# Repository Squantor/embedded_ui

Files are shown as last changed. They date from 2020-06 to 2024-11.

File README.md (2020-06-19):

# General purpose embedded user interface
This repository contains the files for a general purpose embedded system user interface.
## Structure
* [Electronics](https://github.com/Squantor/embedded_ui/blob/master/electronics/README.md) contains the UI PCB with LCD and buttons
* [Software](https://github.com/Squantor/embedded_ui/blob/master/software/README.md) contains the test and demo software for the user interface
* [Mechanical](https://github.com/Squantor/embedded_ui/blob/master/mechanical/README.md) contains drawings of UI covers
## Checking out
This project makes extensive use of submodules, use ```git clone --recurse-submodules https://github.com/Squantor/$(PROJECT).git``` to clone the repository and its submodules in one go.

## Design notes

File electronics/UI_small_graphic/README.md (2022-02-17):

# Small graphical user interface
This PCB is a small graphical user interface with a few buttons.
# HSI (Hardware Software Interface)
This applies to a project that has a embedded software component. Describe what each pin/bus does, what it is connected to, what its function is and some "safe" behaviour when starting up.
## TODO's
Still some things need to be done:
* Produce at [Aisler](https://aisler.net/)
* Assemble
* Test & characterise
* update Readme.md with pictures and BOM
## BOM
* The standard aliexpress OLED displays with 128x64 or 128x32 resolution.
* I2C port expander (PCF device)
## Pictures
TODO

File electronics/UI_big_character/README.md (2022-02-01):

# Big character user interface
User interface for the a wide range of applications consisting of a 2 by 16 character LCD, 4 buttons and a rotary encoder.
## TODO's
* Assemble
* Test & characterise
* update Readme.md with pictures and BOM

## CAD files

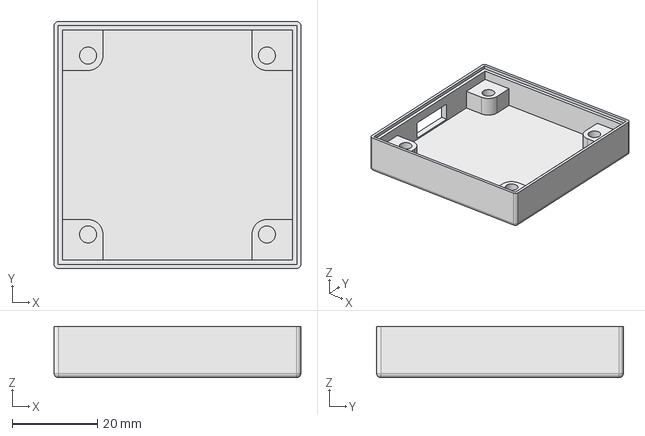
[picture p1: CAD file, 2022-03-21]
mechanical/UI_small_graphic_box/UI_small_graphic.FCStd
58.0 x 58.0 x 12.0 mm

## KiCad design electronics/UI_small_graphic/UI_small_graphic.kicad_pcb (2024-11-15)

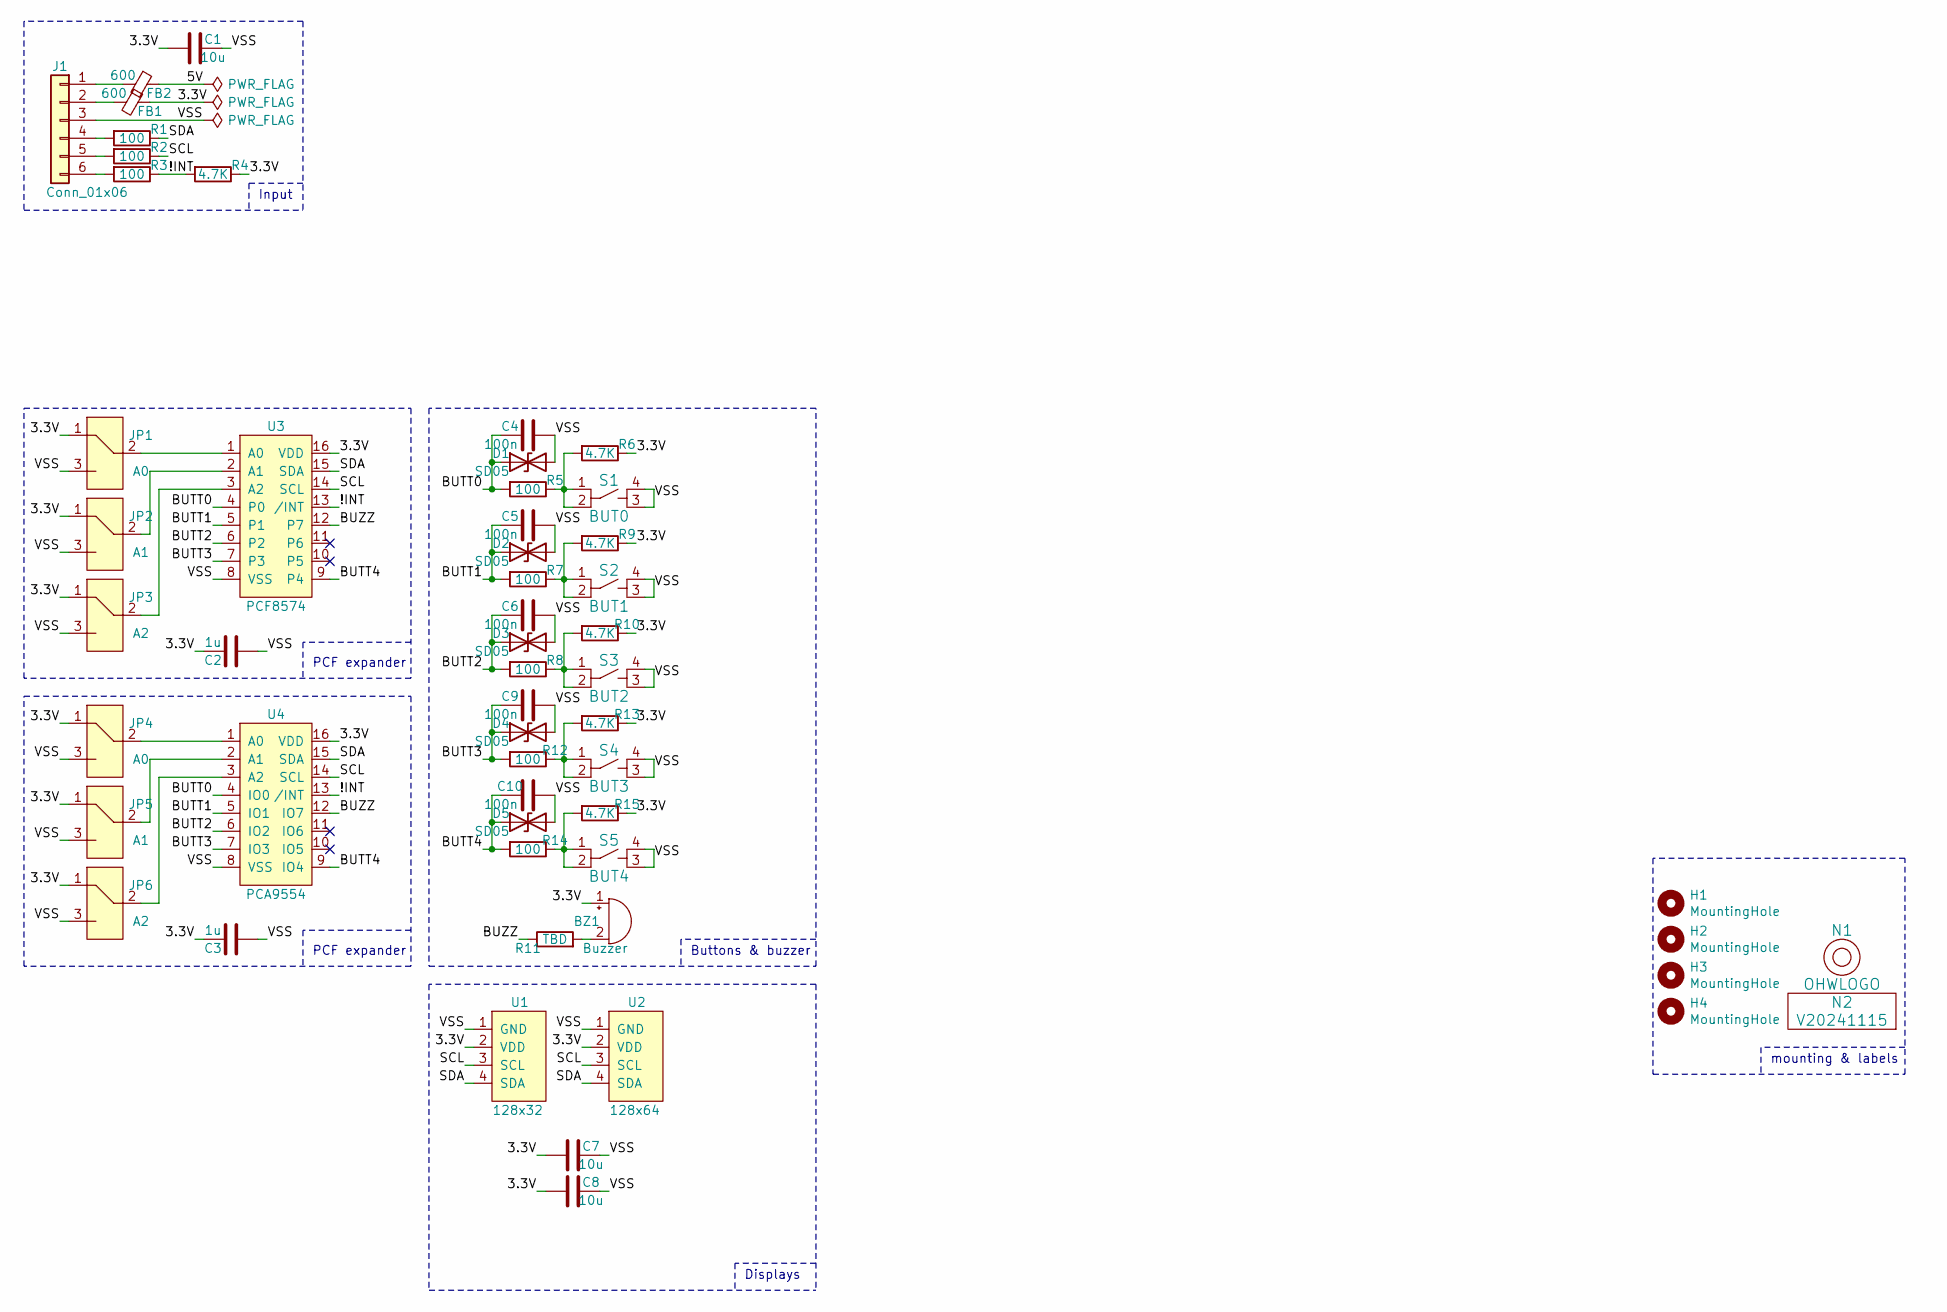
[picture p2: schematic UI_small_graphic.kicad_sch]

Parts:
BZ1: Buzzer; Buzzer_12x9.5RM7.6
C1, C7, C8: 10u; C_0603
C2, C3: 1u; C_0603
C4, C5, C6, C9, C10: 100n; C_0603
D1, D2, D3, D4, D5: SD05; SOD_323_onsemi
FB1, FB2: 600; L_0603
H1, H2, H3, H4: MountingHole; MountingHole_3.2mm_M3_Pad_Via
J1: Conn_01x06; JST_PH_S6B-PH-K_1x06_P2.00mm_Horizontal
JP1, JP4: A0; solder_jumper_0603_3way_12conn
JP2, JP5: A1; solder_jumper_0603_3way_12conn
JP3, JP6: A2; solder_jumper_0603_3way_12conn
N1: OHWLOGO; OSHW-Symbol_6.7x6mm_SilkScreen
N2: V20241115; Label_Generic
R1, R2, R3, R5, R7, R8, R12, R14: 100; R_0603_hand
R4, R6, R9, R10, R13, R15: 4.7K; R_0603_hand
R11: TBD; R_0603_hand
S1: BUT0; Omron_B3F-1052
S2: BUT1; Omron_B3F-1052
S3: BUT2; Omron_B3F-1052
S4: BUT3; Omron_B3F-1052
S5: BUT4; Omron_B3F-1052
U1: 128x32; OLED_128x32
U2: 128x64; OLED_132in_128x96
U3: PCF8574; SOT162-1-NXP
U4: PCA9554; SOT403-1-NXP

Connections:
/3.3V: BZ1.1 (-), C1.2, C2.1, C3.1, C7.2, C8.2, FB1.1, JP1.1, JP2.1, JP3.1, JP4.1, JP5.1, JP6.1, R4.1, R6.1, R9.1, R10.1, R13.1, R15.1, U1.2 (VDD), U2.2 (VDD), U3.16 (VDD), U4.16 (VDD)
/5V: FB2.1
/!INT: R3.1, R4.2, U3.13 (/INT), U4.13 (/INT)
/BUTT0: C4.1, D1.1 (A1), R5.2, U3.4 (P0), U4.4 (IO0)
/BUTT1: C5.1, D2.1 (A1), R7.2, U3.5 (P1), U4.5 (IO1)
/BUTT2: C6.1, D3.1 (A1), R8.2, U3.6 (P2), U4.6 (IO2)
/BUTT3: C9.1, D4.1 (A1), R12.2, U3.7 (P3), U4.7 (IO3)
/BUTT4: C10.1, D5.1 (A1), R14.2, U3.9 (P4), U4.9 (IO4)
/BUZZ: R11.1, U3.12 (P7), U4.12 (IO7)
/SCL: R2.1, U1.3 (SCL), U2.3 (SCL), U3.14 (SCL), U4.14 (SCL)
/SDA: R1.1, U1.4 (SDA), U2.4 (SDA), U3.15 (SDA), U4.15 (SDA)
/VSS: C1.1, C2.2, C3.2, C4.2, C5.2, C6.2, C7.1, C8.1, C9.2, C10.2, D1.2 (A2), D2.2 (A2), D3.2 (A2), D4.2 (A2), D5.2 (A2), J1.3, JP1.3, JP2.3, JP3.3, JP4.3, JP5.3, JP6.3, S1.3, S1.4, S2.3, S2.4, S3.3, S3.4, S4.3, S4.4, S5.3, S5.4, U1.1 (GND), U2.1 (GND), U3.8 (VSS), U4.8 (VSS)
unnamed: BZ1.2 (+), R11.2
unnamed: FB1.2, J1.2
unnamed: FB2.2, J1.1
unnamed: J1.4, R1.2
unnamed: J1.5, R2.2
unnamed: J1.6, R3.2
unnamed: JP1.2, U3.1 (A0)
unnamed: JP2.2, U3.2 (A1)
unnamed: JP3.2, U3.3 (A2)
unnamed: JP4.2, U4.1 (A0)
unnamed: JP5.2, U4.2 (A1)
unnamed: JP6.2, U4.3 (A2)
unnamed: R5.1, R6.2, S1.1, S1.2
unnamed: R7.1, R9.2, S2.1, S2.2
unnamed: R8.1, R10.2, S3.1, S3.2
unnamed: R12.1, R13.2, S4.1, S4.2
unnamed: R14.1, R15.2, S5.1, S5.2

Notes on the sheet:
Input
mounting & labels
PCF expander
Buttons & buzzer
Displays

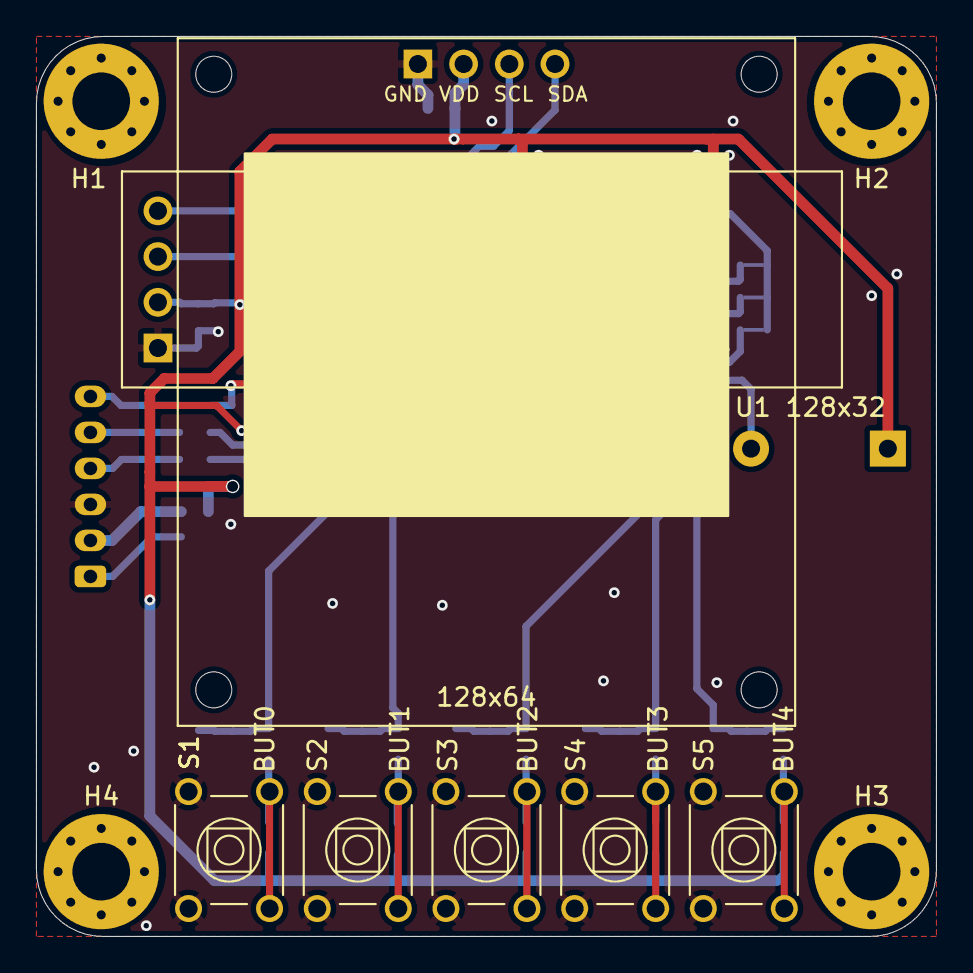
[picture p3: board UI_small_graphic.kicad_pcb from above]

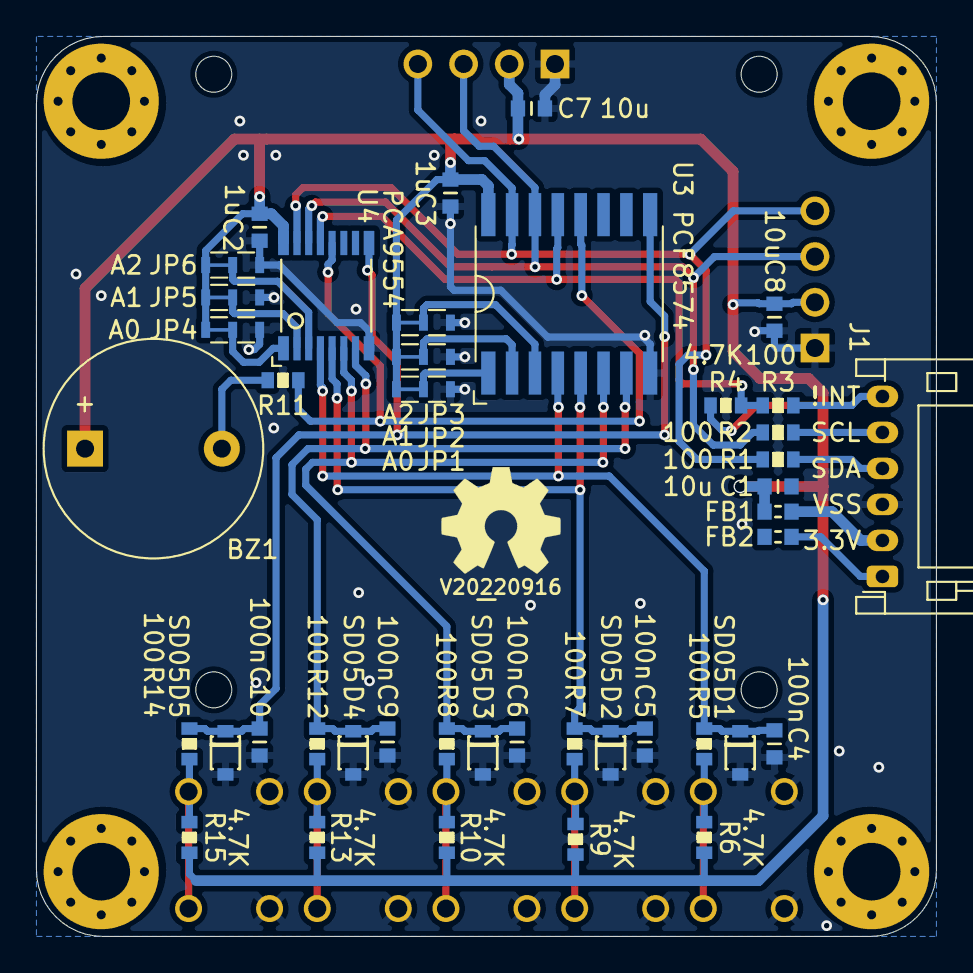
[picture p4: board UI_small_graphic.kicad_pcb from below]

Board: 2 copper layers, 50.0 x 50.0 mm, 55 parts (44 on the bottom side), 28 nets.

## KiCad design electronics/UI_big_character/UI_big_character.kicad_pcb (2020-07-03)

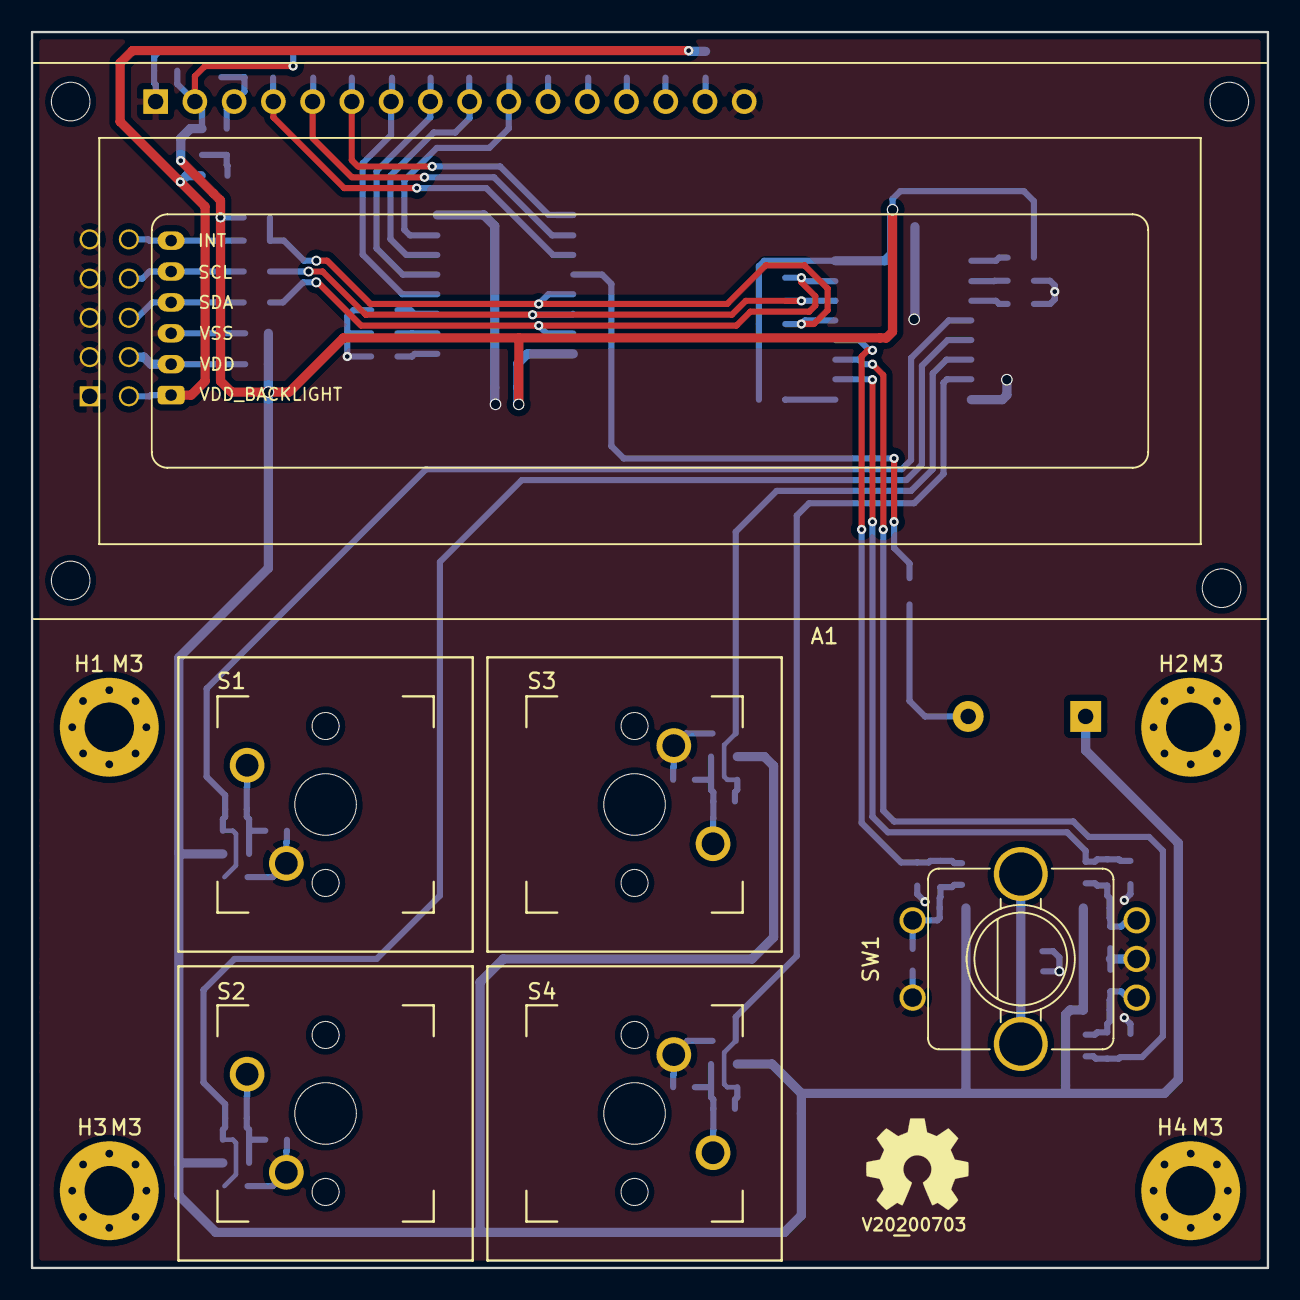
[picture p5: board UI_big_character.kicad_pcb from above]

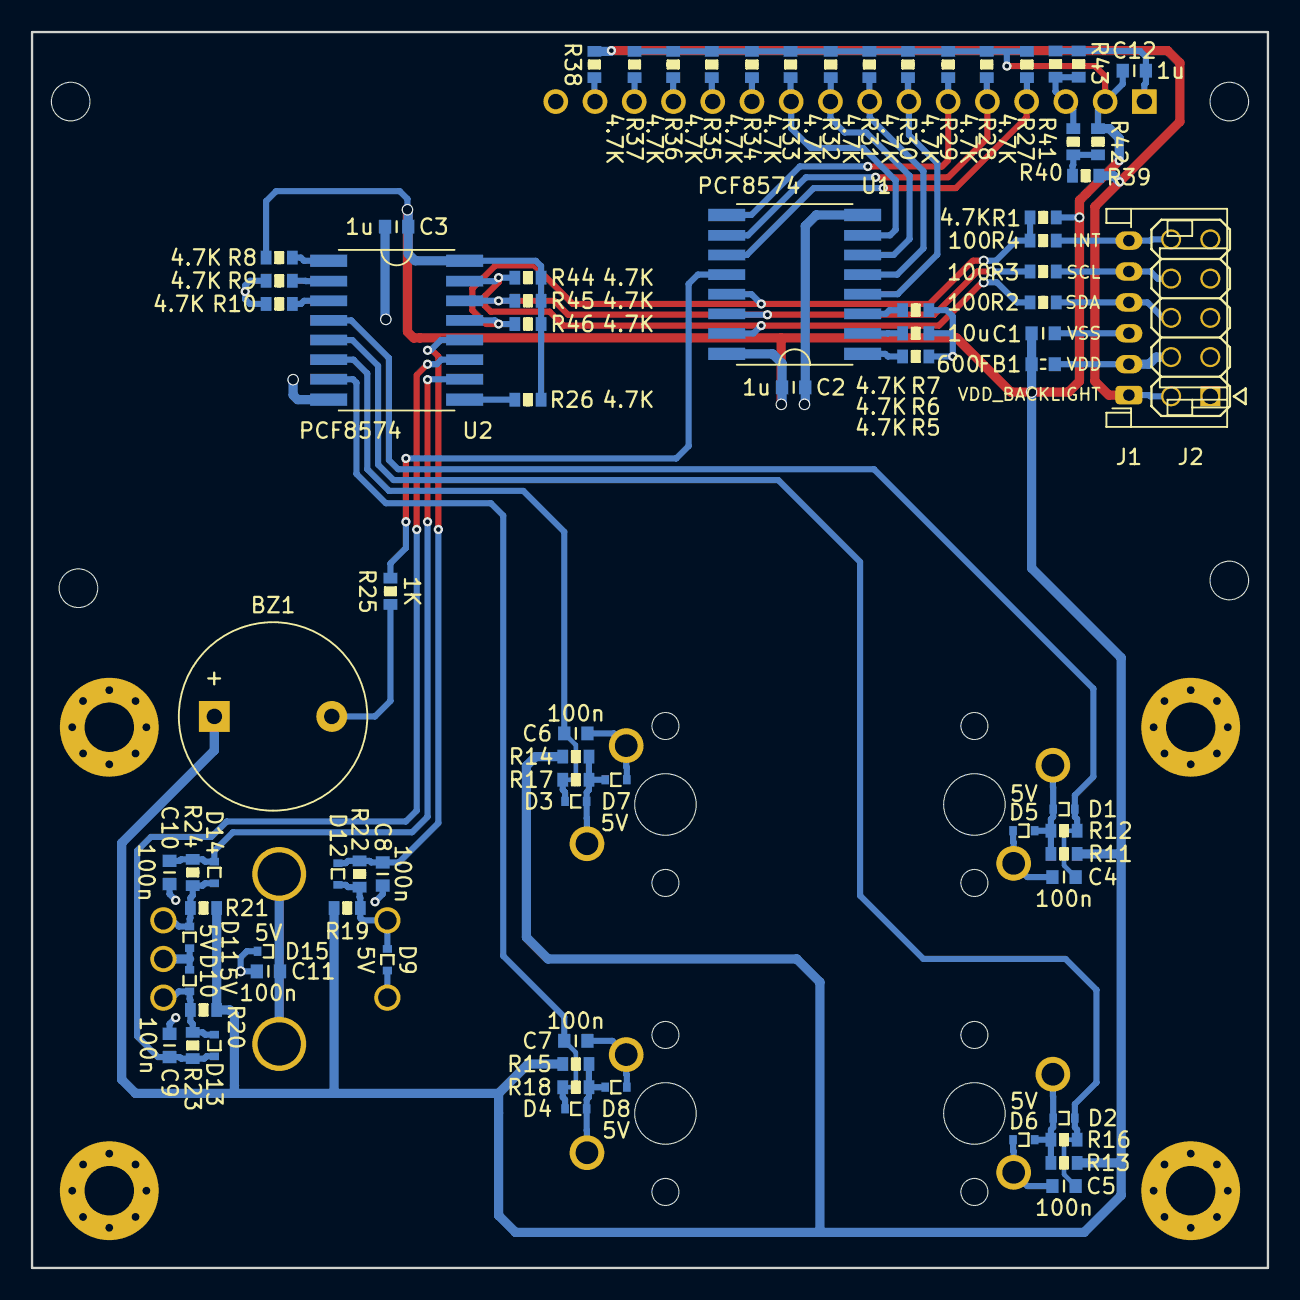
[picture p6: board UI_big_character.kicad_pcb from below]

Board: 2 copper layers, 80.0 x 80.0 mm, 91 parts (79 on the bottom side), 48 nets.

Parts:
A1: LCM1602; LCM1602K
BZ1: Buzzer; Buzzer_12x9.5RM7.6
C1: 10u; C_0603
C2, C3, C12: 1u; C_0603
C4, C5, C6, C7, C8, C9, C10, C11: 100n; C_0603
D1, D2, D3, D4, D12, D13, D14: RB521S-30; SOD-523
D5, D6, D7, D8, D9, D10, D11, D15: 5V; SOD-523
FB1: 600; L_0603
H1, H2, H3, H4: M3; MountingHole_3.2mm_M3_Pad_Via
J1: Conn_01x06; JST_PH_S6B-PH-K_1x06_P2.00mm_Horizontal
J2: Conn_02x05_Odd_Even; Header-0254-2X05-H010
N1: OHWLOGO; OSHW-Symbol_6.7x6mm_SilkScreen
N2: V20200703; Label_Generic
R1, R5, R6, R7, R8, R9, R10, R26, R27, R28, R29, R30, R31, R32, R33, R34, R35, R36, R37, R44, R45, R46: 4.7K; R_0603_hand
R2, R3, R4: 100; R_0603_hand
R11, R12, R13, R14, R15, R16, R17, R18, R19, R20, R21, R22, R23, R24, R38, R40, R41: TBD; R_0603_hand
R25: 1K; R_0603_hand
R39, R42: 0; R_0603_hand
R43: NTC?; R_0603_hand
S1, S2, S3, S4: Cherry Blue; MXOnly-1U-NoLED
SW1: ALPS_EC11E18244A5; ALPS_EC11E_style5
U1, U2: PCF8574; SOT162-1-NXP

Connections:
/!INT: R1.1, R4.1, R46.1, U1.13, U2.13
/!INT_RAW: J1.6, J2.10, R4.2
/Button_00: C4.1, D1.1, R12.1, U2.4
/Button_01: C5.1, D2.1, R16.1, U2.5
/Button_02: C6.1, D3.1, R17.1, U2.6
/Button_03: C7.1, D4.1, R18.1, U2.7
/Buzzer: R25.2, U1.12
/DB0: A1.7, R30.1, U1.4
/DB1: A1.8, R31.1, U1.5
/DB2: A1.9, R32.1, U1.6
/DB3: A1.10, R33.1, U1.7
/DB4: A1.11, R34.1
/DB5: A1.12, R35.1
/DB6: A1.13, R36.1
/DB7: A1.14, R37.1
/E: A1.6, R29.1, U1.9
/RS: A1.4, R27.1, U1.11
/RW: A1.5, R28.1, U1.10
/Rotary_A: D10.1, D13.2, R20.1, R23.2, SW1.A
/Rotary_A_filtered: C9.1, D13.1, R23.1, U2.11
/Rotary_B: D11.1, D14.2, R21.1, R24.2, SW1.B
/Rotary_B_filtered: C10.1, D14.1, R24.1, U2.10
/Rotary_push: D9.1, D12.2, R19.1, R22.2, SW1.E
/Rotary_push_filtered: C8.1, D12.1, R22.1, U2.12
/Rotary_shield: C11.2, D15.1, SW1.S
/SCL: R3.1, R45.1, U1.14, U2.14
/SCL_RAW: J1.5, J2.8, R3.2
/SDA: R2.1, R44.1, U1.15, U2.15
/SDA_RAW: J1.4, J2.6, R2.2
/VDD: A1.2, BZ1.1, C1.1, C2.1, C3.1, C12.1, FB1.1, R1.2, R8.2, R11.2, R13.2, R14.2, R15.2, R19.2, R20.2, R21.2, R26.1, R27.2, R28.2, R29.2, R30.2, R31.2, R32.2, R33.2, R34.2, R35.2, R36.2, R37.2, R42.1, R44.2, R45.2, R46.2, U1.16, U2.16
/VDD_BACKLIGHT: J1.1, J2.2, R38.2, R39.1
/VDD_RAW: FB1.2, J1.2, J2.4
/VO: A1.3, R40.2, R41.1, R43.1
/VSS: A1.1, A1.16, C1.2, C2.2, C3.2, C4.2, C5.2, C6.2, C7.2, C8.2, C9.2, C10.2, C11.1, C12.2, D5.2, D6.2, D7.2, D8.2, D9.2, D10.2, D11.2, D15.2, J1.3, J2.1, J2.3, J2.5, J2.7, J2.9, R5.2, R6.2, R7.2, R9.2, R10.2, R41.2, R43.2, S1.1, S2.1, S3.1, S4.1, SW1.C, SW1.D, U1.8, U2.8
unnamed: A1.15, R38.1
unnamed: BZ1.2, R25.1
unnamed: D1.2, D5.1, R11.1, R12.2, S1.2
unnamed: D2.2, D6.1, R13.1, R16.2, S2.2
unnamed: D3.2, D7.1, R14.1, R17.2, S3.2
unnamed: D4.2, D8.1, R15.1, R18.2, S4.2
unnamed: R5.1, U1.1
unnamed: R6.1, U1.2
unnamed: R7.1, U1.3
unnamed: R8.1, U2.1
unnamed: R9.1, U2.2
unnamed: R10.1, U2.3
unnamed: R26.2, U2.9
unnamed: R39.2, R40.1, R42.2

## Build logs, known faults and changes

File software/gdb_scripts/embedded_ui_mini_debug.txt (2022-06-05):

set print pretty on
set architecture armv6
file bin/embedded_ui_mini/debug/embedded_ui_mini.elf
target extended-remote /dev/ttyACM0
monitor swdp_scan
attach 1
set mem inaccessible-by-default off
set {int}0x40048000 = 2
load bin/embedded_ui_mini/debug/embedded_ui_mini.elf
set {int}0x40048000 = 2
compare-sections
b main

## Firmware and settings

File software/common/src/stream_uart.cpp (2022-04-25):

/*
MIT License

Copyright (c) 2019 Bart Bilos

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
THE SOFTWARE IS PROVIDED "AS IS", WITHOUT WARRANTY OF ANY KIND, EXPRESS OR
IMPLIED, INCLUDING BUT NOT LIMITED TO THE WARRANTIES OF MERCHANTABILITY,
FITNESS FOR A PARTICULAR PURPOSE AND NONINFRINGEMENT. IN NO EVENT SHALL THE
AUTHORS OR COPYRIGHT HOLDERS BE LIABLE FOR ANY CLAIM, DAMAGES OR OTHER
LIABILITY, WHETHER IN AN ACTION OF CONTRACT, TORT OR OTHERWISE, ARISING FROM,
OUT OF OR IN CONNECTION WITH THE SOFTWARE OR THE USE OR OTHER DEALINGS IN THE
SOFTWARE.
*/
/*
Datastream that points to the user facing UART interface
*/

#include <results.h>
#include <stream_uart.hpp>
#include <board.hpp>
#include <mcu_ll.h>

const static char streamUartName[] = "uartStream";
result writeUart(const char *c);
result readUart(char *c);
const datastreamChar_t streamUart = {writeUart, readUart, streamUartName};

result writeUart(const char *c) {
  while ((usartGetStatus(UART_DEBUG) & USART_STAT_TXRDY) == 0)
    ;
  usartSendData(UART_DEBUG, *c);
  return noError;
}

result readUart(char *c) {
  if ((usartGetStatus(UART_DEBUG) & USART_STAT_RXRDY) != 0) {
    *c = usartReadData(UART_DEBUG);
    return noError;
  } else
    return streamEmtpy;
}

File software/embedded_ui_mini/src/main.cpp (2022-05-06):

/*
SPDX-License-Identifier: MIT

Copyright (c) 2022 Bart Bilos
For conditions of distribution and use, see LICENSE file
*/
#include <board.hpp>
#include <events.hpp>
#include <application.hpp>
#include <ui_demo.hpp>

extern "C" {
void SysTick_Handler(void) {
  postEvent(eventTick);
}

void PIN_INT0_IRQHandler(void) {
  pinintClearIntStatus(PININT, PININT_BUTTON_INT);
  postEvent(eventExpInt);
}
}

int main() {
  boardInit();
  applicationInit();
  while (1) {
    applicationProcessEvents();
    __WFI();
  }
}

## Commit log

2020-06-19 added initial project landing
2020-06-19 added user interface hardware (from the soldering station
    [user_interface.kicad_pcb, user_interface.sch]
2020-07-03 updated versionnumber
    [user_interface.kicad_pcb, user_interface.sch]
2020-07-03 WIP adding labels to connectors
    [user_interface.kicad_pcb]
2020-07-03 WIP labels now on top layer too, placement completed, time to route
    [user_interface.kicad_pcb]
2020-07-03 routing done
    [user_interface.kicad_pcb]
2020-07-03 minor silk placement
    [user_interface.kicad_pcb]
2022-01-28 updated submodules for new board
2022-02-01 started with small userinterface
    [UI_small_graphic.kicad_pcb, UI_small_graphic.sch]
2022-02-01 renamed first user interface
    [UI_big_character.kicad_pcb, UI_big_character.sch]
2022-02-01 started with PCB dimensions and input connector
    [UI_small_graphic.kicad_pcb, UI_small_graphic.sch]
2022-02-02 added displays to board
    [UI_small_graphic.kicad_pcb, UI_small_graphic.sch]
2022-02-07 added PCA I/O expander
    [UI_small_graphic.sch]
2022-02-07 updated footprints
2022-02-07 added I2C port expanders to PCB
    [UI_small_graphic.kicad_pcb, UI_small_graphic.sch]
2022-02-07 further routing
    [UI_small_graphic.kicad_pcb]
2022-02-10 added buzzer
    [UI_small_graphic.sch]
2022-02-11 routing completed
    [UI_small_graphic.kicad_pcb]
2022-02-11 routing completed, added decoupling caps for displays, started with silk placement
    [UI_small_graphic.kicad_pcb, UI_small_graphic.sch]
2022-02-13 added new versionnumber, updated silk placement top, WIP bottom
    [UI_small_graphic.kicad_pcb, UI_small_graphic.sch]
2022-02-13 bottom silk placed
    [UI_small_graphic.kicad_pcb]
2022-02-17 small changes preparing for production
    [UI_small_graphic.kicad_pcb, UI_small_graphic.sch]
2022-03-08 updated schematic
    [UI_small_graphic.sch]
2022-03-08 updated PCB library
2022-03-10 generated plots
    [UI_small_graphic.kicad_pcb, UI_small_graphic.sch]
2022-03-10 updated plot settings
    [UI_small_graphic.kicad_pcb]
2022-03-21 added template parametric box
    [UI_small_graphic.FCStd]
2022-03-21 connector hole better position
    [UI_small_graphic.FCStd]
2022-04-05 small UI modification?
    [UI_small_graphic.kicad_pcb]
2022-04-05 fixed UI dimensions
    [UI_small_graphic.kicad_pcb]
2022-04-05 updated PCB library
2022-04-25 got USART output working correctly, ported over SSD1306 demo
    [embedded_ui_mini.hpp, main.cpp, nuclone_mini_ui.cpp]
2022-04-29 switching over to event based handling
2022-04-29 added empty button handler method, but first need to update libmcull
2022-04-30 updated libmcull to have the pin interrupts for LPC8XX
2022-05-06 WIP button handling
2022-05-08 I2C readout
2022-06-03 conversion to kicad 6
    [UI_small_graphic.kicad_pcb, UI_small_graphic.kicad_sch, UI_small_graphic.sch]
2022-06-03 button handling stuff
2022-06-03 updated versionnumber, fixed DRC errors
    [UI_small_graphic.kicad_pcb, UI_small_graphic.kicad_sch]
2022-06-03 fixed via
    [UI_small_graphic.kicad_pcb]
2022-06-03 fixed 3d models
    [UI_small_graphic.kicad_pcb]
2022-06-03 pcb component updates
    [UI_small_graphic.kicad_pcb]
2022-06-04 switched to framebuffered SSD1306 driver
2022-07-24 fixed footprint library
2022-07-29 switched buttons
    [UI_small_graphic.kicad_sch]
2022-07-29 added 2 buttons extra, we have space for them
    [UI_small_graphic.kicad_sch]
2022-07-29 added new displays and addional buttons
    [UI_small_graphic.kicad_pcb]
2022-08-28 placed ESD parts, silk placed
    [UI_small_graphic.kicad_pcb, UI_small_graphic.kicad_sch]
2024-11-15 updated to new kicad version, updated mechanical dimensions to newer nuclone hole pattern
    [UI_small_graphic.kicad_pcb, UI_small_graphic.kicad_sch]
